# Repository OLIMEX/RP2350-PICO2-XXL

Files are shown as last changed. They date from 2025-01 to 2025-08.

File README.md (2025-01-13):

# RP2350-PICO2-XXL
RP2350B PICO2 development board exposing 48 GPIO

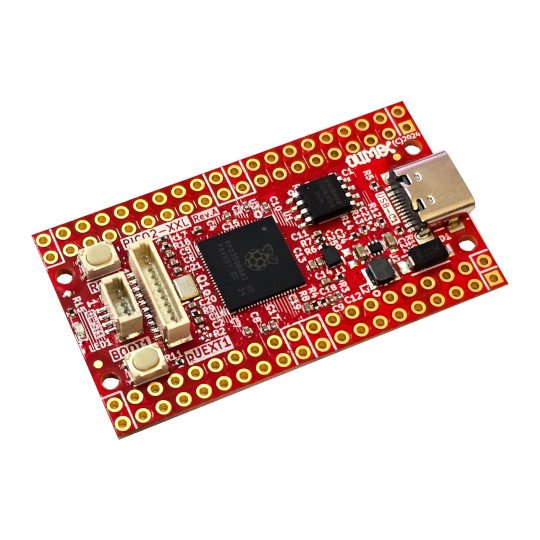
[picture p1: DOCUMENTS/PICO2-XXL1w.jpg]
PICO2-XXL1w


https://www.olimex.com/Products/RaspberryPi/PICO/PICO2-XXL/

## Licensee
* Hardware is released under CERN Open Hardware Licence Version 2 - Strongly Reciprocal
* Software is released under GPL V3 Licensee
* Documentation is released under CC BY-SA 4.0

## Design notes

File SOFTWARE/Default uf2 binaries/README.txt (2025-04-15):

Default uf2 binaries are the binaries we program the boards during testing and manufacturing.

These were last updated at the end of January before hardware revision B was released.

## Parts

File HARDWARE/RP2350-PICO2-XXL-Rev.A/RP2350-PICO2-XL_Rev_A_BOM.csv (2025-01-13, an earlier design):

Quantity | Value | Footprint | Reference
2 | YTS-A016-X | YTS-A016-X | BOOT1, RST1
13 | 100nF/10V/20%/X5R/C0402 | C_0402_5MIL_DWS | C1, C3, C4, C5, C6, C7, C8, C9, C10, C11, C12, C15, C17
5 | 4.7uF/10V/20%/X5R/C0402 | C_0402_5MIL_DWS | C13, C14, C16, C18, C19
2 | 27pF/50V/5%/C0G/C0402 | C_0402_5MIL_DWS | C20, C21
2 | 22uF/6.3V/20%/X5R/C0603 | C_0603_5MIL_DWS | C22, C24
1 | 1N5822/SS34/SMA | SMA-KA | D1
1 | 3.3uH/2.0A/DCR=140mR/20%/2.00x1.60x1.00mm/L2016(PIM201610-3R3MTS00) | L_2016_MM | L1
1 | 1.0uH/2.5A/DCR=30mR/20%/3.00x3.00x1.50mm/CD32(SWPA3015S1R0MT) | CD32 | L2
1 | LED/GREEN/0603 | LED_0603_KA | LED1
1 | Q12MHz/18pF/30ppm/4P/3.2x2.5mm(ABM8-12.000MHZ-D2Y-T) | TSX-3.2x2.5mm_GND(3) | Q1
1 | SH1.0-4P-180D | BM04B-SRSS-TB | QWST1
1 | 10k/R0402 | R_0402_5MIL_DWS | R1
1 | 33R/R0402 | R_0402_5MIL_DWS | R3
1 | 200R/1%/R0402 | R_0402_5MIL_DWS | R4
2 | 5.1k/1%/R0402 | R_0402_5MIL_DWS | R5, R10
2 | 27R/R0402 | R_0402_5MIL_DWS | R6, R7
1 | 1.3R/1%/R0402 | R_0402_5MIL_DWS | R8
2 | 1k/R0402 | R_0402_5MIL_DWS | R9, R11
1 | 1M/R0402 | R_0402_5MIL_DWS | R12
1 | 220k/R0402 | R_0402_5MIL_DWS | R13
1 | 49.9k/1%/R0402 | R_0402_5MIL_DWS | R14
3 | 2.2k/R0402 | R_0402_5MIL_DWS | R15, R17, R18
1 | W25Q16JVSSIQ | SO-8_208mil | U1
1 | TPS62A02ADRLR(SOT-563-6) | SOT-563-6 | U2
1 | RP2350B(QFN-80_10.00x10.00x0.90mm_P0.4mm) | QFN-80_10.00x10.00x0.90mm_P0.4mm | U3
1 | USB-C-16P-F(A40-00119-A52-12) | USB2.0_TYPE-C(A40-00119-A52-12)_Paste | USB-C1
1 | SH1.0-10P-180D | BM10B-SRSS-TB | pUEXT1

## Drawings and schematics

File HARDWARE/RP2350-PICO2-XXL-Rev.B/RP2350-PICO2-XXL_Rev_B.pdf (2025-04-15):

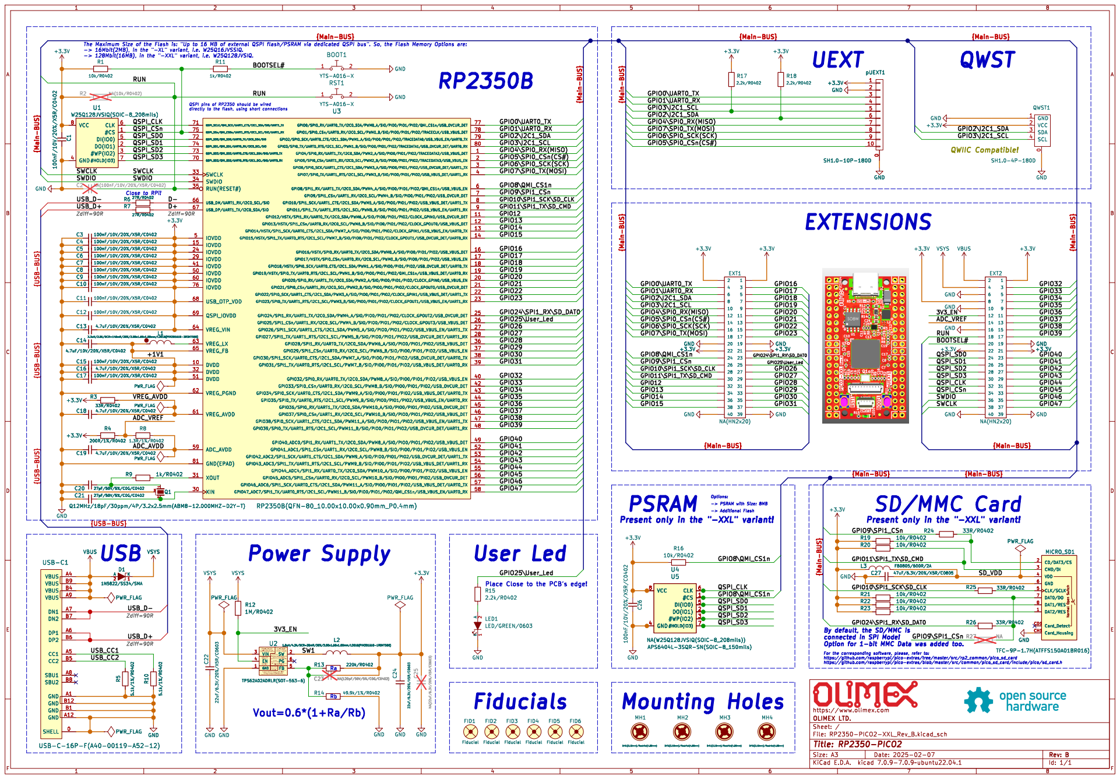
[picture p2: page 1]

Zdiff=90R {USB-BUS} {USB-BUS} {Main-BUS}
+3.3V GND

QSPI pins of RP2350 should be wired

Place Close to the PCB's edge!

Cout=(10~22)uF/6.3V/X5Rþÿ(Vout"e1.8V). 22uFRecommended! Cout=22uF/6.3V/X5Rþÿ(1.2V"dVout<1.8V) Cout=44uF/6.3V/X5Rþÿ(0.6V"dVout<1.2V) DCR<50mR

In casea loweroutputrippleisdesired,higheroutputcapacitancecanhelpreducetheripple. Lx=1.0uH

https://github.com/raspberrypi/pico-extras/blob/master/src/common/pico_sd_card/include/pico/sd_card.h

Donotfloat. Enablecontrol. FB Input Current,I(FB)=100nA(max) FeedbackReferenceVoltage,V(REF)=0.6V
Rb mustnotbehigherthanþÿ100k© toprovideacceptablenoisesensitivity. ShutdownCurrentI(SHDN)=0.01-2uA

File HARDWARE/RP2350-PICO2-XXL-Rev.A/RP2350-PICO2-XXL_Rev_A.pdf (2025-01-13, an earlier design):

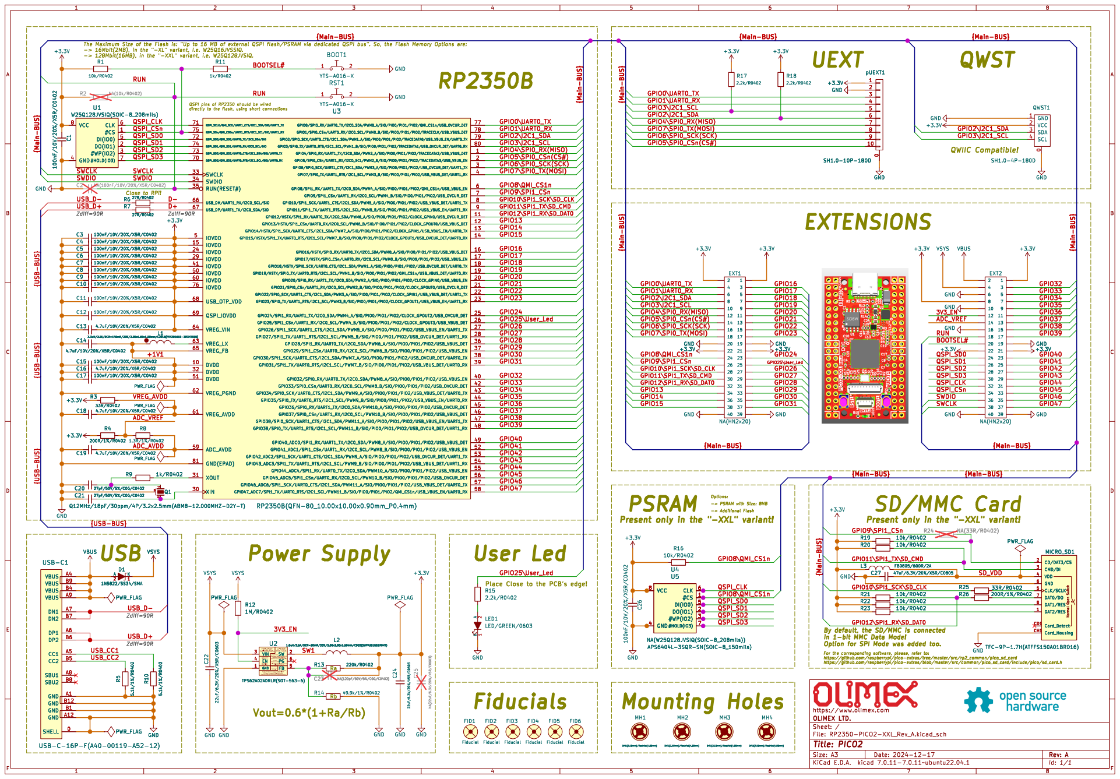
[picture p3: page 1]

QSPI pins of RP2350 should be wired
directly to the flash, using short connections

Place Close to the PCB's edge! Power Supply

Donotfloat. Enablecontrol. FB Input Current,I(FB)=100nA(max) FeedbackReferenceVoltage,V(REF)=0.6V
Rb mustnotbehigherthanþÿ100k© toprovideacceptablenoisesensitivity. ShutdownCurrentI(SHDN)=0.01-2uA
SwitchingFrequency 2.4MHz TPS62A02ADRLR V(ENH)=1.2V

In casea loweroutputrippleisdesired,higheroutputcapacitancecanhelpreducetheripple. Lx=1.0uH
Cout=(10~22)uF/6.3V/X5Rþÿ(Vout"e1.8V). 22uFRecommended! Cout=22uF/6.3V/X5Rþÿ(1.2V"dVout<1.8V) Cout=44uF/6.3V/X5Rþÿ(0.6V"dVout<1.2V) DCR<50mR

TPS62A02ADRLR(SOT-563-6)
Rb Vout=0.6*(1+Ra/Rb)

File: RP2350-PICO2-XXL_Rev_A.kicad_sch Sheet: / OLIMEX LTD. https://www.olimex.com

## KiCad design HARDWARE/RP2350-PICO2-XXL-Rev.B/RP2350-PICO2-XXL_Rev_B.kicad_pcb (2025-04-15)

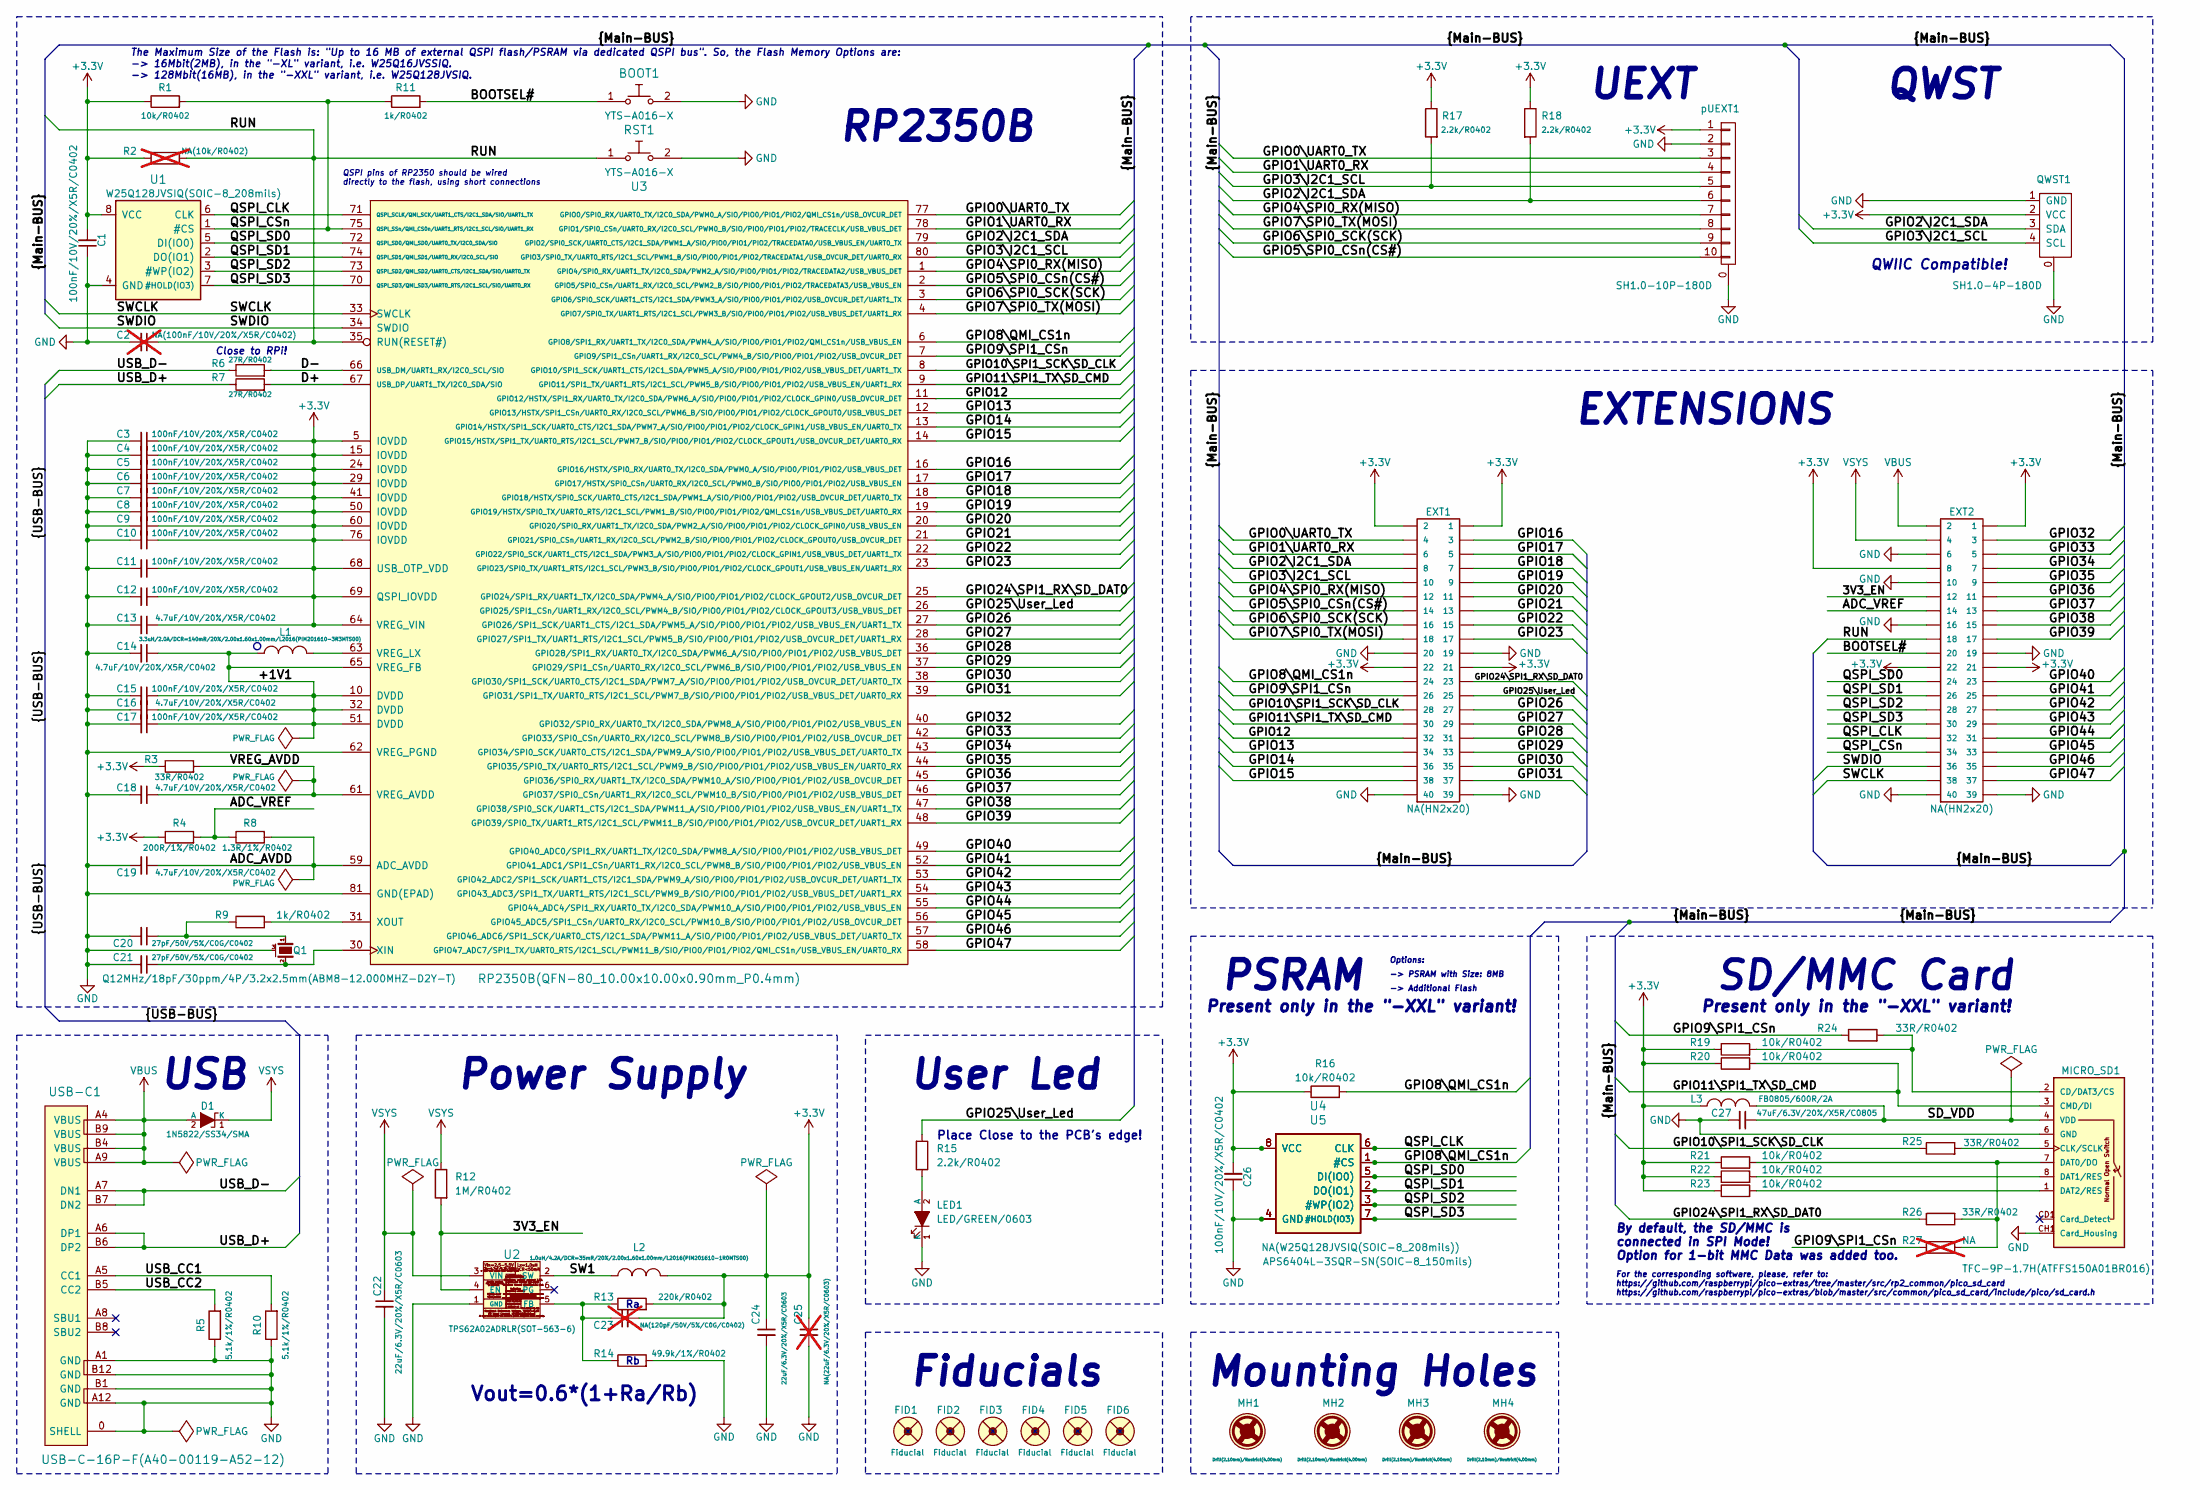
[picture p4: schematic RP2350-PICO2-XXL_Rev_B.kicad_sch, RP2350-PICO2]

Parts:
BOOT1: YTS-A016-X
C1, C3, C4, C5, C6, C7, C8, C9, C10, C11, C12, C15, C17, C26: 100nF/10V/20%/X5R/C0402; C_0402_5MIL_DWS
C2: NA(100nF/10V/20%/X5R/C0402); C_0402_5MIL_DWS; not fitted
C13, C14, C16, C18, C19: 4.7uF/10V/20%/X5R/C0402; C_0402_5MIL_DWS
C20, C21: 27pF/50V/5%/C0G/C0402; C_0402_5MIL_DWS
C22, C24: 22uF/6.3V/20%/X5R/C0603; C_0603_5MIL_DWS
C23: NA(120pF/50V/5%/C0G/C0402); C_0402_5MIL_DWS; not fitted
C25: NA(22uF/6.3V/20%/X5R/C0603); C_0603_5MIL_DWS; not fitted
C27: 47uF/6.3V/20%/X5R/C0805; C_0805_5MIL_DWS
D1: 1N5822/SS34/SMA; SMA-KA
EXT1, EXT2: NA(HN2x20); HN2x20
FID1, FID4: Fiducial; Fiducial1x3_Paste
FID2, FID3, FID5, FID6: Fiducial; Fiducial1x3
L1: 3.3uH/2.0A/DCR=140mR/20%/2.00x1.60x1.00mm/L2016(P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; L_2016_MM
L2: 1.0uH/4.2A/DCR=35mR/20%/2.00x1.60x1.00mm/L2016(PI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; L_2016_MM
L3: FB0805/600R/2A; L_0805_5MIL_DWS
LED1: LED/GREEN/0603; LED_0603_KA
MH1, MH2, MH3, MH4: Drill(2.10mm)/Restrict(4.00mm); Mounting_Hole_Drill-2.1mm_Clerance-4mm
MICRO_SD1: TFC-9P-1.7H(ATFFS150A01BR016); uSD(TFC-9P-1.xH(ATFFS150A01BR016))
Q1: Q12MHz/18pF/30ppm/4P/3.2x2.5mm(ABM8-12.000MHZ-D2Y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; TSX-3.2x2.5mm_GND(3)
QWST1: SH1.0-4P-180D; BM04B-SRSS-TB
R1, R16, R19, R20, R21, R22, R23: 10k/R0402; R_0402_5MIL_DWS
R2: NA(10k/R0402); R_0402_5MIL_DWS; not fitted
R3, R24, R25, R26: 33R/R0402; R_0402_5MIL_DWS
R4: 200R/1%/R0402; R_0402_5MIL_DWS
R5, R10: 5.1k/1%/R0402; R_0402_5MIL_DWS
R6, R7: 27R/R0402; R_0402_5MIL_DWS
R8: 1.3R/1%/R0402; R_0402_5MIL_DWS
R9, R11: 1k/R0402; R_0402_5MIL_DWS
R12: 1M/R0402; R_0402_5MIL_DWS
R13: 220k/R0402; R_0402_5MIL_DWS
R14: 49.9k/1%/R0402; R_0402_5MIL_DWS
R15, R17, R18: 2.2k/R0402; R_0402_5MIL_DWS
R27: NA; R_0402_5MIL_DWS; not fitted
RST1: YTS-A016-X
U1: W25Q128JVSIQ(SOIC-8_208mils); SO-8_208mil
U2: TPS62A02ADRLR(SOT-563-6); SOT-563-6
U3: RP2350B(QFN-80_10.00x10.00x0.90mm_P0.4mm); QFN-80_10.00x10.00x0.90mm_P0.4mm
U4: NA(W25Q128JVSIQ(SOIC-8_208mils)); SO-8_208mil
U5: APS6404L-3SQR-SN(SOIC-8_150mils); SO-8
USB-C1: USB-C-16P-F(A40-00119-A52-12); USB2.0_TYPE-C(A40-00119-A52-12)_Paste
pUEXT1: SH1.0-10P-180D; BM10B-SRSS-TB

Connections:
+3.3V: C1.2, C3.1, C4.1, C5.1, C6.1, C7.1, C8.1, C9.1, C10.1, C11.1, C12.1, C13.1, C23.2, C24.1, C25.1, C26.2, EXT1.1, EXT1.2, EXT1.21, EXT1.22, EXT2.1, EXT2.8, EXT2.21, EXT2.22, L2.1, L3.1, QWST1.2 (VCC), R1.1, R2.1, R3.1, R4.1, R13.2, R16.1, R17.1, R18.1, R19.1, R20.1, R21.1, R22.1, R23.1, U1.8 (VCC), U3.5 (IOVDD), U3.15 (IOVDD), U3.24 (IOVDD), U3.29 (IOVDD), U3.41 (IOVDD), U3.50 (IOVDD), U3.60 (IOVDD), U3.64 (VREG_VIN), U3.68 (USB_OTP_VDD), U3.69 (QSPI_IOVDD), U3.76 (IOVDD), U4.8 (VCC), U5.8 (VCC), pUEXT1.1
/3V3_EN: EXT2.12, R12.2, U2.4 (EN)
/+1V1: C14.1, C15.1, C16.1, C17.1, L1.1, U3.10 (DVDD), U3.32 (DVDD), U3.51 (DVDD), U3.65 (VREG_FB)
/ADC_AVDD: C19.1, R8.2, U3.59 (ADC_AVDD)
/ADC_VREF: EXT2.14, R4.2, R8.1
/BOOTSEL#: BOOT1.1, EXT2.20, R11.2
/D+: R7.2, U3.67 (USB_DP/UART1_TX/I2C0_SDA/SIO)
/D-: R6.2, U3.66 (USB_DM/UART1_RX/I2C0_SCL/SIO)
/GPIO0\UART0_TX: EXT1.4, U3.77 (GPIO0/SPI0_RX/UART0_TX/I2C0_SDA/PWM0_A/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), pUEXT1.3
/GPIO1\UART0_RX: EXT1.6, U3.78 (GPIO1/SPI0_CSn/UART0_RX/I2C0_SCL/PWM0_B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), pUEXT1.4
/GPIO2\I2C1_SDA: EXT1.8, QWST1.3 (SDA), R18.2, U3.79 (GPIO2/SPI0_SCK/UART0_CTS/I2C1_SDA/PWM1_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), pUEXT1.6
/GPIO3\I2C1_SCL: EXT1.10, QWST1.4 (SCL), R17.2, U3.80 (GPIO3/SPI0_TX/UART0_RTS/I2C1_SCL/PWM1_B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), pUEXT1.5
/GPIO4\SPI0_RX(MISO): EXT1.12, U3.1 (GPIO4/SPI0_RX/UART1_TX/I2C0_SDA/PWM2_A/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), pUEXT1.7
/GPIO5\SPI0_CSn(CS#): EXT1.14, U3.2 (GPIO5/SPI0_CSn/UART1_RX/I2C0_SCL/PWM2_B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), pUEXT1.10
/GPIO6\SPI0_SCK(SCK): EXT1.16, U3.3 (GPIO6/SPI0_SCK/UART1_CTS/I2C1_SDA/PWM3_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), pUEXT1.9
/GPIO7\SPI0_TX(MOSI): EXT1.18, U3.4 (GPIO7/SPI0_TX/UART1_RTS/I2C1_SCL/PWM3_B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), pUEXT1.8
/GPIO8\QMI_CS1n: EXT1.24, R16.2, U3.6 (GPIO8/SPI1_RX/UART1_TX/I2C0_SDA/PWM4_A/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), U4.1 (#CS), U5.1 (#CS)
/GPIO9\SPI1_CSn: EXT1.26, R24.1, R27.1, U3.7 (GPIO9/SPI1_CSn/UART1_RX/I2C0_SCL/PWM4_B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)
/GPIO10\SPI1_SCK\SD_CLK: EXT1.28, R25.1, U3.8 (GPIO10/SPI1_SCK/UART1_CTS/I2C1_SDA/PWM5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)
/GPIO11\SPI1_TX\SD_CMD: EXT1.30, MICRO_SD1.3 (CMD/DI), R20.2, U3.9 (GPIO11/SPI1_TX/UART1_RTS/I2C1_SCL/PWM5_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)
/GPIO12: EXT1.32, U3.11 (GPIO12/HSTX/SPI1_RX/UART0_TX/I2C0_SDA/P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)
/GPIO13: EXT1.34, U3.12 (GPIO13/HSTX/SPI1_CSn/UART0_RX/I2C0_SCL/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)
/GPIO14: EXT1.36, U3.13 (GPIO14/HSTX/SPI1_SCK/UART0_CTS/I2C1_SDA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)
/GPIO15: EXT1.38, U3.14 (GPIO15/HSTX/SPI1_TX/UART0_RTS/I2C1_SCL/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)
/GPIO16: EXT1.3, U3.16 (GPIO16/HSTX/SPI0_RX/UART0_TX/I2C0_SDA/P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)
/GPIO17: EXT1.5, U3.17 (GPIO17/HSTX/SPI0_CSn/UART0_RX/I2C0_SCL/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)
/GPIO18: EXT1.7, U3.18 (GPIO18/HSTX/SPI0_SCK/UART0_CTS/I2C1_SDA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)
/GPIO19: EXT1.9, U3.19 (GPIO19/HSTX/SPI0_TX/UART0_RTS/I2C1_SCL/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)
/GPIO20: EXT1.11, U3.20 (GPIO20/SPI0_RX/UART1_TX/I2C0_SDA/PWM2_A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)
/GPIO21: EXT1.13, U3.21 (GPIO21/SPI0_CSn/UART1_RX/I2C0_SCL/PWM2_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)
/GPIO22: EXT1.15, U3.22 (GPIO22/SPI0_SCK/UART1_CTS/I2C1_SDA/PWM3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)
/GPIO23: EXT1.17, U3.23 (GPIO23/SPI0_TX/UART1_RTS/I2C1_SCL/PWM3_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)
/GPIO24\SPI1_RX\SD_DAT0: EXT1.23, R26.1, U3.25 (GPIO24/SPI1_RX/UART1_TX/I2C0_SDA/PWM4_A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)
/GPIO25\User_Led: EXT1.25, R15.2, U3.26 (GPIO25/SPI1_CSn/UART1_RX/I2C0_SCL/PWM4_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)
/GPIO26: EXT1.27, U3.27 (GPIO26/SPI1_SCK/UART1_CTS/I2C1_SDA/PWM5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)
/GPIO27: EXT1.29, U3.28 (GPIO27/SPI1_TX/UART1_RTS/I2C1_SCL/PWM5_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)
/GPIO28: EXT1.31, U3.36 (GPIO28/SPI1_RX/UART0_TX/I2C0_SDA/PWM6_A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)
/GPIO29: EXT1.33, U3.37 (GPIO29/SPI1_CSn/UART0_RX/I2C0_SCL/PWM6_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)
/GPIO30: EXT1.35, U3.38 (GPIO30/SPI1_SCK/UART0_CTS/I2C1_SDA/PWM7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)
/GPIO31: EXT1.37, U3.39 (GPIO31/SPI1_TX/UART0_RTS/I2C1_SCL/PWM7_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)
/GPIO32: EXT2.3, U3.40 (GPIO32/SPI0_RX/UART0_TX/I2C0_SDA/PWM8_A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)
/GPIO33: EXT2.5, U3.42 (GPIO33/SPI0_CSn/UART0_RX/I2C0_SCL/PWM8_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)
/GPIO34: EXT2.7, U3.43 (GPIO34/SPI0_SCK/UART0_CTS/I2C1_SDA/PWM9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)
/GPIO35: EXT2.9, U3.44 (GPIO35/SPI0_TX/UART0_RTS/I2C1_SCL/PWM9_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)
/GPIO36: EXT2.11, U3.45 (GPIO36/SPI0_RX/UART1_TX/I2C0_SDA/PWM10_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)
/GPIO37: EXT2.13, U3.46 (GPIO37/SPI0_CSn/UART1_RX/I2C0_SCL/PWM10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)
/GPIO38: EXT2.15, U3.47 (GPIO38/SPI0_SCK/UART1_CTS/I2C1_SDA/PWM1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)
/GPIO39: EXT2.17, U3.48 (GPIO39/SPI0_TX/UART1_RTS/I2C1_SCL/PWM11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)
/GPIO40: EXT2.23, U3.49 (GPIO40_ADC0/SPI1_RX/UART1_TX/I2C0_SDA/P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)
/GPIO41: EXT2.25, U3.52 (GPIO41_ADC1/SPI1_CSn/UART1_RX/I2C0_SCL/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)
/GPIO42: EXT2.27, U3.53 (GPIO42_ADC2/SPI1_SCK/UART1_CTS/I2C1_SDA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)
/GPIO43: EXT2.29, U3.54 (GPIO43_ADC3/SPI1_TX/UART1_RTS/I2C1_SCL/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)
/GPIO44: EXT2.31, U3.55 (GPIO44_ADC4/SPI1_RX/UART0_TX/I2C0_SDA/P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)
/GPIO45: EXT2.33, U3.56 (GPIO45_ADC5/SPI1_CSn/UART0_RX/I2C0_SCL/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)
/GPIO46: EXT2.35, U3.57 (GPIO46_ADC6/SPI1_SCK/UART0_CTS/I2C1_SDA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)
/GPIO47: EXT2.37, U3.58 (GPIO47_ADC7/SPI1_TX/UART0_RTS/I2C1_SCL/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)
/QSPI_CLK: EXT2.32, U1.6 (CLK), U3.71 (QSPI_SCLK/QMI_SCK/UART1_CTS/I2C1_SDA/SI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), U4.6 (CLK), U5.6 (CLK)
/QSPI_CSn: EXT2.34, R1.2, R11.1, U1.1 (#CS), U3.75 (QSPI_SSn/QMI_CS0n/UART1_RTS/I2C1_SCL/SI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)
/QSPI_SD0: EXT2.24, U1.5 (DI(IO0)), U3.72 (QSPI_SD0/QMI_SD0/UART0_TX/I2C0_SDA/SIO), U4.5 (DI(IO0)), U5.5 (DI(IO0))
/QSPI_SD1: EXT2.26, U1.2 (DO(IO1)), U3.74 (QSPI_SD1/QMI_SD1/UART0_RX/I2C0_SCL/SIO), U4.2 (DO(IO1)), U5.2 (DO(IO1))
/QSPI_SD2: EXT2.28, U1.3 (#WP(IO2)), U3.73 (QSPI_SD2/QMI_SD2/UART0_CTS/I2C1_SDA/SIO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), U4.3 (#WP(IO2)), U5.3 (#WP(IO2))
/QSPI_SD3: EXT2.30, U1.7 (#HOLD(IO3)), U3.70 (QSPI_SD3/QMI_SD3/UART0_RTS/I2C1_SCL/SIO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), U4.7 (#HOLD(IO3)), U5.7 (#HOLD(IO3))
/RUN: C2.1, EXT2.18, R2.2, RST1.1, U3.35 (RUN(RESET#))
/SD_VDD: C27.1, L3.2, MICRO_SD1.4 (VDD)
/SW1: L2.2, U2.2 (SW)
/SWCLK: EXT2.38, U3.33 (SWCLK)
/SWDIO: EXT2.36, U3.34 (SWDIO)
/USB_CC1: R10.2, USB-C1.A5 (CC1)
/USB_CC2: R5.2, USB-C1.B5 (CC2)
/USB_D+: R7.1, USB-C1.A6 (DP1), USB-C1.B6 (DP2)
/USB_D-: R6.1, USB-C1.A7 (DN1), USB-C1.B7 (DN2)
/VREG_AVDD: C18.1, R3.2, U3.61 (VREG_AVDD)
GND: BOOT1.2, C1.1, C2.2, C3.2, C4.2, C5.2, C6.2, C7.2, C8.2, C9.2, C10.2, C11.2, C12.2, C13.2, C14.2, C15.2, C16.2, C17.2, C18.2, C19.2, C20.2, C21.2, C22.2, C24.2, C25.2, C26.1, C27.2, EXT1.19, EXT1.20, EXT1.39, EXT1.40, EXT2.6, EXT2.10, EXT2.16, EXT2.19, EXT2.39, EXT2.40, LED1.1 (K), MICRO_SD1.6 (GND), MICRO_SD1.CH1 (Card_Housing), Q1.3 (case), QWST1.0, QWST1.1 (GND), R5.1, R10.1, R14.2, RST1.2, U1.4 (GND), U2.1 (GND), U3.62 (VREG_PGND), U3.81 (GND(EPAD)), U4.4 (GND), U5.4 (GND), USB-C1.0 (SHELL), USB-C1.A1 (GND), USB-C1.A12 (GND), USB-C1.B1 (GND), USB-C1.B12 (GND), pUEXT1.0, pUEXT1.2
unnamed: C20.1, Q1.1, R9.1
unnamed: LED1.2 (A), R15.1
unnamed: MICRO_SD1.2 (CD/DAT3/CS), R19.2, R24.2
unnamed: MICRO_SD1.5 (CLK/SCLK), R25.2
unnamed: MICRO_SD1.7 (DAT0/DO), R21.2, R26.2, R27.2
unnamed: MICRO_SD1.8 (DAT1/RES), R22.2
unnamed: MICRO_SD1.1 (DAT2/RES), R23.2
unnamed: C23.1, R13.1, R14.1, U2.5 (FB)
unnamed: L1.2, U3.63 (VREG_LX)
unnamed: C21.1, Q1.2, U3.30 (XIN)
unnamed: R9.2, U3.31 (XOUT)
VBUS: D1.2 (A), EXT2.2, USB-C1.A4 (VBUS), USB-C1.A9 (VBUS), USB-C1.B4 (VBUS), USB-C1.B9 (VBUS)
VSYS: C22.1, D1.1 (K), EXT2.4, R12.1, U2.3 (VIN)

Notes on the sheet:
Present only in the "-XXL" variant!
EXTENSIONS
QSPI pins of RP2350 should be wired directly to the flash, using short connections
-> PSRAM with Size: 8MB
By default, the SD/MMC is connected in SPI Mode! Option for 1-bit MMC Data was added too.
The Maximum Size of the Flash is: "Up to 16 MB of external QSPI flash/PSRAM via dedicated QSPI bus". So, the Flash Memory Options are: -> 16Mbit(2MB), in the "-XL" variant, i.e. W25Q16JVSSIQ. -> 128Mbit(16MB), in the "-XXL" variant, i.e. W25Q128JVSIQ.
SD/MMC Card
QWST
USB
User Led
For the corresponding software, please, refer to: https://github.com/raspberrypi/pico-extras/tree/master/src/rp2_common/pico_sd_card https://github.com/raspberrypi/pico-extras/blob/master/src/common/pico_sd_card/include/pico/sd_card.h
Options:
-> Additional Flash
QWIIC Compatible!
Place Close to the PCB's edge!
Close to RPi!
RP2350B
Vout=0.6*(1+Ra/Rb)
Mounting Holes
Power Supply
PSRAM
Fiducials
UEXT

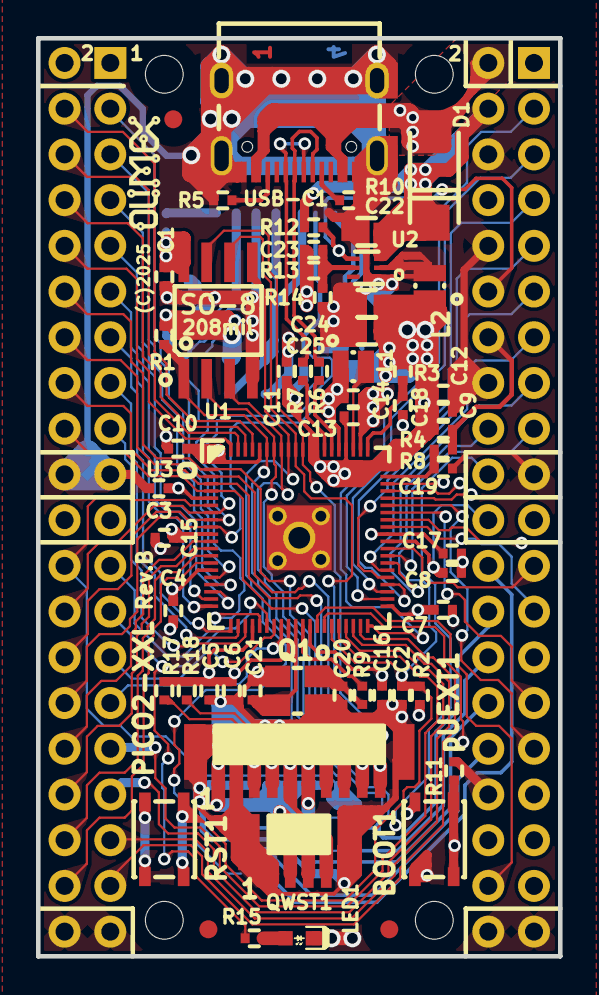
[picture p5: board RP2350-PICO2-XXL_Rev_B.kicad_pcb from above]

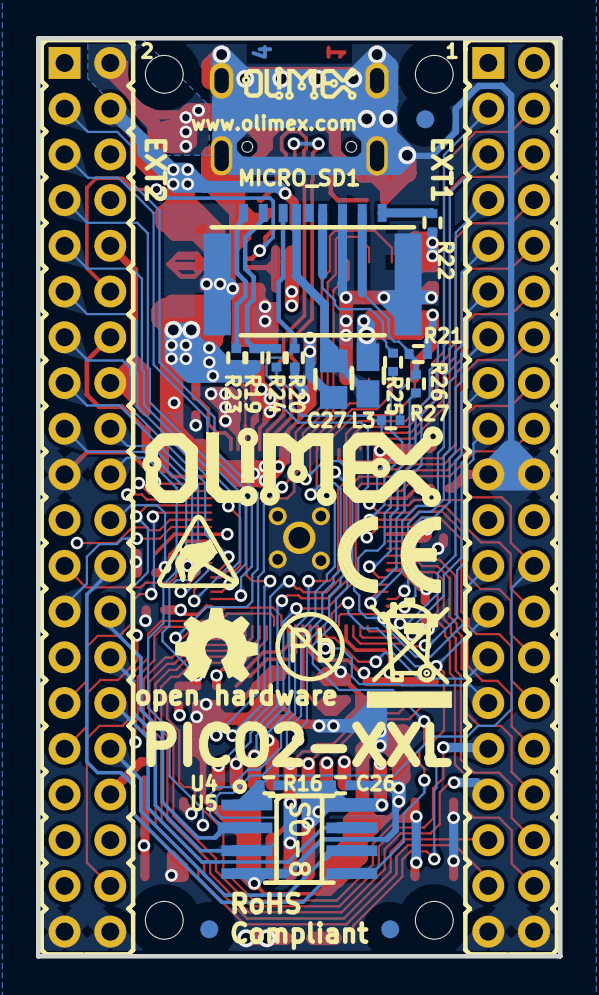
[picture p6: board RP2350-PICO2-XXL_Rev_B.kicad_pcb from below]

Board: 4 copper layers, 29.0 x 51.0 mm, 91 parts (28 on the bottom side), 86 nets.

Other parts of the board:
Logo_OLIMEX_80, Logo_OLIMEX_80-Bot: Logo_OLIMEX_80
Logo_OLIMEX_TB: Logo_OLIMEX_TB
Sign_Antistatic_Small: Sign_Antistatic; Sign_Antistatic_4.5mmX2.8mm
Sign_CE: CE_Sign
Sign_OSHW_7.3x6.0mm: Sign_OSHW_7.3x6.0mm; Sign_OSHW_7.3x6.0mmn
Sign_PB-Free: Sign_PB-Free
Sign_RecycleBin_1: Sign_RecycleBin_1

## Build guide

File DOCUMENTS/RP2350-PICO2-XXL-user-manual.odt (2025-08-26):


RP2350-PICO2-XL

RP2350-PICO2-XXL

User Manual

Document 2.1 August 2025 www.olimex.com

# Introduction to RP2350-PICO2-XXL

RP2350-PICO2-XXL (https://www.olimex.com/Products/RaspberryPi/PICO/PICO2-XXL/open-source-hardware) is a re-design of the popular “Raspberry Pi Pico 2” board with these improvements:

- RP2350B Dual Cortex-M33 or dual RISC-V @ 150MHz
- All 48 RP2350 GPIOs exposed to the user
- USB-C connector for data and powering – it allows more current to be supplied to the board
- DCDC power supply voltage regulator 3.3V 2A (3A peak)
- 2MB or 16MB flash memory versions (-XL and -XXL variants)
- Extra 8MB PSRAM in the -XXL variant
- Micro SD card connector in the -XXL variant
- BOOT and RESET buttons
- Four-layer board for better noise immunity and USB differential pair routing
- UEXT connector (pUEXT 1.0 mm step connector)
- Qwiic/Stemma connector
- Status LED
- Dimensions: (50 x 28)mm ~ (1.97 x 1.10)"

Notice

The two board variants RP2350-PICO2-XL (https://www.olimex.com/Products/RaspberryPi/PICO/RP2350-PICO2-XL/open-source-hardware) and RP2350-PICO2-XXL (https://www.olimex.com/Products/RaspberryPi/PICO/PICO2-XXL/open-source-hardware) share the same PCB and silksreen! The three differences between -XL and -XXL variants are that:

- the -XXL variant has PSRAM,the -XL variant – no PSRAM;

- the -XXL variant has micro SD card, the -XL variant – no micro SD card connector;

- the -XXL has 16MB of flash memory, the flash memory of the -XL variant is only 2MB.

# Order codes for RP2350-PICO2-XXL and accessories

RP2350-PICO2-XL (https://www.olimex.com/Products/RaspberryPi/PICO/RP2350-PICO2-XL/open-source-hardware) industrial grade RP2350-PICO2 board with 48 GPIOs exposed

RP2350-PICO2-XXL (https://www.olimex.com/Products/RaspberryPi/PICO/RP2350-PICO2-XL/open-source-hardware) includes everything in XL, bigger flash, extra 8MB PSRAM, and extra microSD card

USB-CABLE-AM-USB3-C (https://www.olimex.com/Products/Components/Cables/USB-CABLE-AM-USB3-C/) high quality USB 3.0 cable with type C connector for power and programming

pUEXT pack of cables (https://www.olimex.com/Products/Modules/Adapters/pUEXT-CABLE-10-10-200MM/) pack of 3pcs 200mm pUEXT cables

UEXT-MPQ (https://www.olimex.com/Products/Modules/Adapters/UEXT-MPQ/open-source-hardware) converter board from pUEXT to UEXT

UEXT-PQ (https://www.olimex.com/Products/Modules/Adapters/UEXT-PQ/open-source-hardware) another converter board from pUEXT

# HARDWARE

## RP2350-PICO2-XXL layout

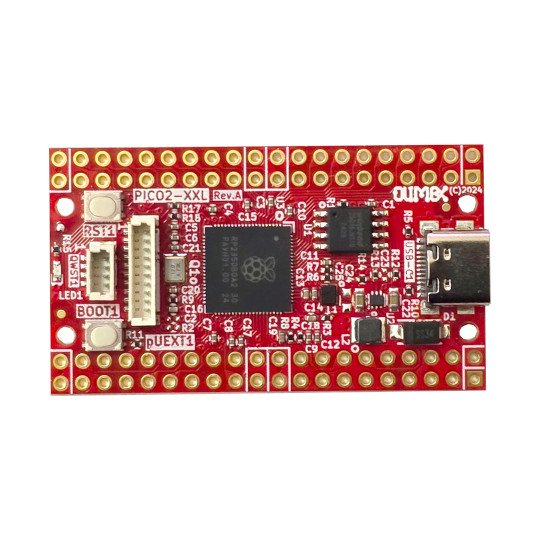
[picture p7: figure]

Top view for both -XL and -XXL

Power supply

USB-C

2MB or 16MB Flash

RP2350B

pUEXT

RST1 reset button

LED

Qwiic Stemma

Boot button

Bottom view for -XL variant:

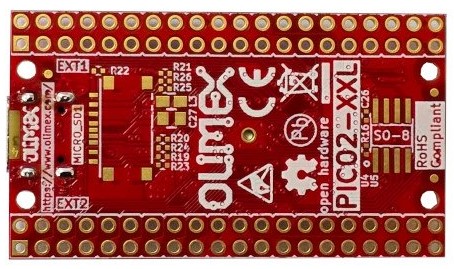
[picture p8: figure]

Bottom view for -XXL variant:

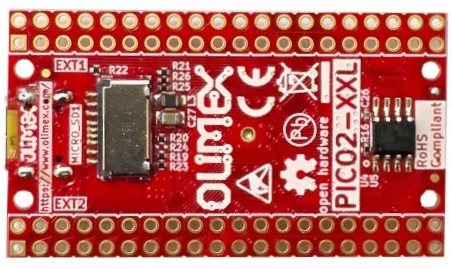
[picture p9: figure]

Micro SD card

8MB PSRAM

## RP2350-PICO2-XXL GPIOs

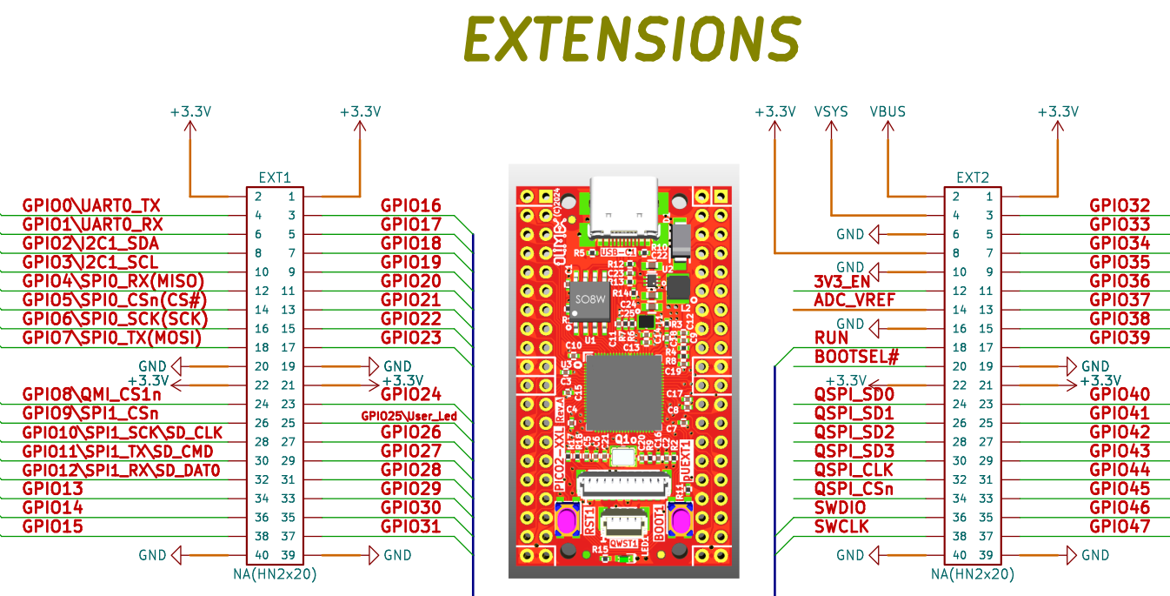
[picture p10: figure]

POWER SUPPLY:

VBUS +5V from, USB-C output

VDD_SYS +5V may be output or input

if you want to use as input i.e. to feed power from external 5V to this line make sure the board is not connected to USB!

when you use it as output i.e. you feed external electronics from it up to 1A @ 5V

+3.3V output which can source up to 2A @ 3.3V

3V3_EN input, when pulled to GND stops the 3.3V DCDC convertor

## RP2350-PICO2-XXL schematics

RP2350-PICO2-XXL (https://www.olimex.com/Products/RaspberryPi/PICO/RP2350-PICO2-XL/open-source-hardware) schematics can be found at GitHub (https://github.com/OLIMEX/RP2350-PICO2-XXL/tree/main/HARDWARE):

https://github.com/OLIMEX/RP2350-PICO2-XXL/tree/main/HARDWARE

## UEXT connector

UEXT connector stands for Universal EXTension connector and contains +3.3V, GND, I2C, SPI, UART signals.

UEXT connector can be in different shapes.

The original UEXT connector is 0.1” 2.54mm step boxed plastic connector. All signals are with 3.3V levels.

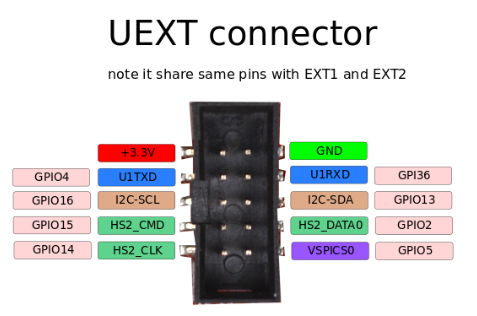
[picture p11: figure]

As the boards become smaller and smaller some smaller packages were introduced too beside the original UEXT connector:

- mUEXT is 1.27 mm step boxed header connector which is with same layout as UEXT;

- pUEXT is 1.0 mm single row connector (this is the connector used in RP2040-PICO30).

Olimex has developed number of MODULES (https://www.olimex.com/Products/Modules/) with this connector. There are temperature, humidity, pressure, magnetic field, light sensors. Modules with LCDs, LED matrix, Relays, Bluetooth, Zigbee, WiFi, GSM, GPS, RFID, RTC, EKG, sensors and etc.

## pUEXT signals

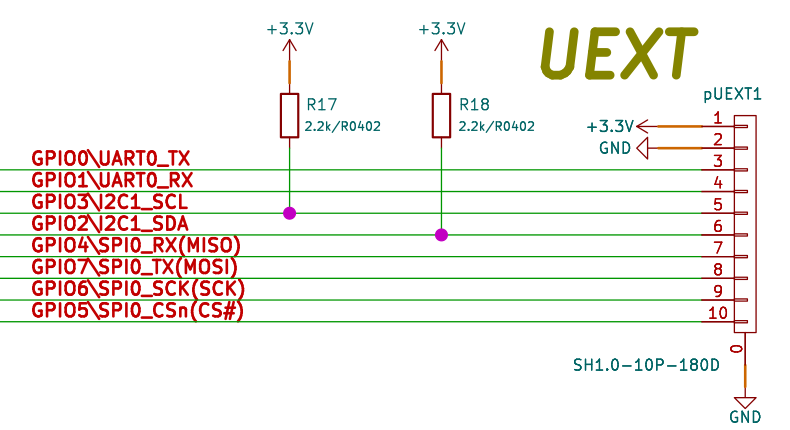
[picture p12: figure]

## Qwiic/Stemma connector

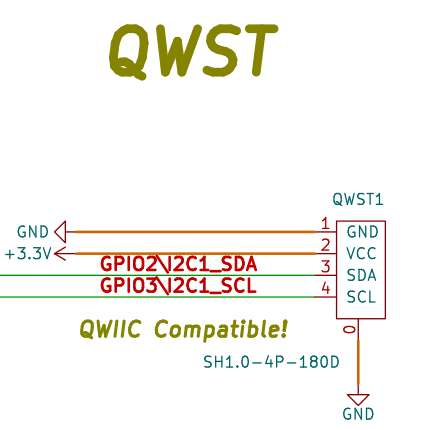
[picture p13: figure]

## Micro SD card connector

In latest hardware revisions (B and newer) the SD card is connected in SPI data mode:

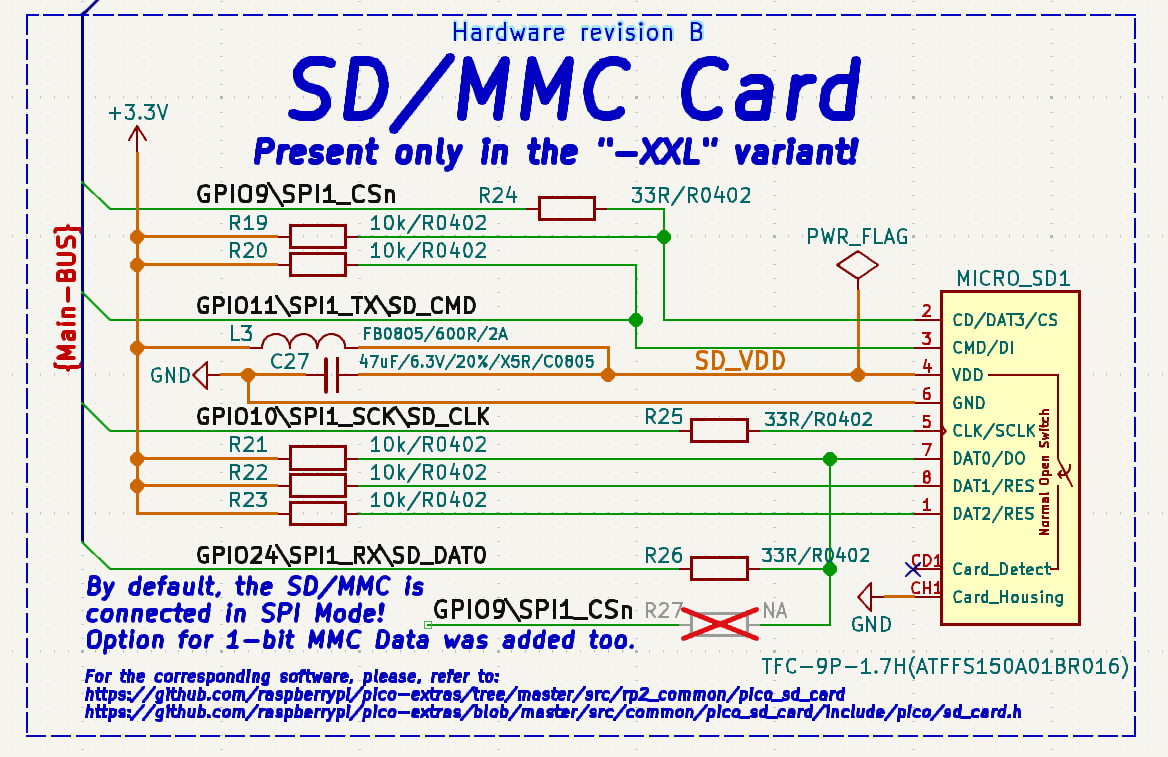
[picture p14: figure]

Notice that in hardware revision A the board was connected in 1-bit MMC data mode.

## PSRAM connection

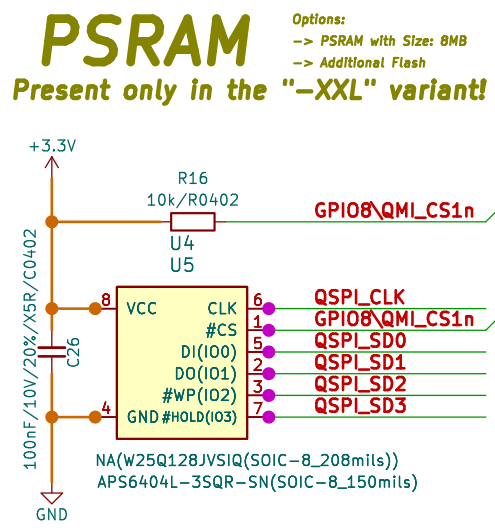
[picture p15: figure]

## LED connection

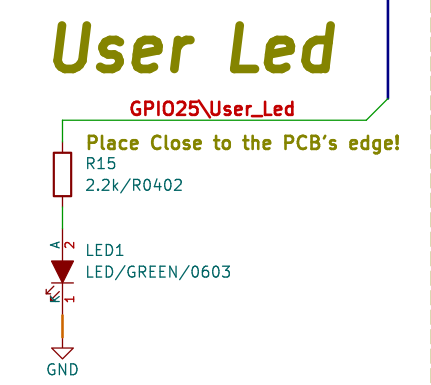
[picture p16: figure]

# SOFTWARE

RP2350-PICO2-XXL uses same software as PICO2

- Raspberry PI SDK, header can be found at this GitHub link (https://github.com/OLIMEX/RP2350-PICO2-XXL/blob/main/SOFTWARE/Pico%20SDK%202.1.1%20header/olimex_rp2350b_pico2.h)
- MicroPython SDK (note that to the current date RP2350B chip support is not implemented in MicroPython and the access of the GPIO30-47 in MicroPython is not implemented.
- CircuitPython from Adafruit – all 48 GPIOs are implemented.

Original production binaries can be found at the GitHub link here (https://github.com/OLIMEX/RP2350-PICO2-XXL/tree/main/SOFTWARE/Default%20uf2%20binaries)

# Document Revision History

Revision 2.1 August 2025

- Improved formatting

Revision 2.0 April 2025

- Added latest schematics

- Improved formatting

Revision 1.0 January 2025

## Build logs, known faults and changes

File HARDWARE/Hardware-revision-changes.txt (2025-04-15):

Deisgn made with KiCAD.

RP2350-PICO2-XXL notable hardware revisions changes:

Hardware revision B:

1. SD card now in SPI mode by default;
2. SD_DAT0 changed from "GPIO12\SPI1_RX\SD_DAT0" to "GPIO24\SPI1_RX\SD_DAT0" to avoid multiplexing;
3. Added R27 to provide an option for 1-bit mode and to change SD_DAT0 to GPIO9\SPI1_CSn;
4. Changed L2 package L_20_16_MM and value 1.0uH/4.2A/DCR=35mR/20%/2.00x1.60x1.00mm/L2016(PIM201610-1R0MTS00).
---

Hardware revision A:

Initial board release.

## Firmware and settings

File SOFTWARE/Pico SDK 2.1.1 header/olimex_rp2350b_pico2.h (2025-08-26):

/*
 * Copyright (c) 2020 Raspberry Pi (Trading) Ltd.
 *
 * SPDX-License-Identifier: BSD-3-Clause
 */

// -----------------------------------------------------
// NOTE: THIS HEADER IS ALSO INCLUDED BY ASSEMBLER SO
//       SHOULD ONLY CONSIST OF PREPROCESSOR DIRECTIVES
// -----------------------------------------------------

// This header may be included by other board headers as "boards/pimoroni_pico_plus2_rp2350.h"

// pico_cmake_set PICO_PLATFORM=rp2350

#ifndef _BOARDS_OLIMEX_PICO2_RP2350B_XXL_H
#define _BOARDS_OLIMEX_PICO2_RP2350B_XXL_H

// For board detection
#define OLIMEX_PICO2_RP2350B_XXL

// --- BOARD SPECIFIC ---

#define UEXT_UART 0
#define UEXT_UART_TX_PIN 0
#define UEXT_UART_RX_PIN 1
#define UEXT_I2C 1
#define UEXT_I2C_SCL_PIN 3
#define UEXT_I2C_SDA_PIN 2
#define UEXT_SPI 0
#define UEXT_SPI0_TX_MOSI_PIN 4
#define UEXT_SPIO_RX_MISO_PIN 7
#define UEXT_SPI0_SCK_PIN 6
#define UEXT_SPI0_CS_PIN 5

#define QWST_I2C 1
#define QWST_I2C_SCL_PIN 3
#define QWST_I2C_SDA_PIN 2

#define OLIMEX_PICO2_RP2350B_PSRAM_CS_PIN 8

// --- UART ---
#ifndef PICO_DEFAULT_UART
#define PICO_DEFAULT_UART 0
#endif
#ifndef PICO_DEFAULT_UART_TX_PIN
#define PICO_DEFAULT_UART_TX_PIN UEXT_UART_TX_PIN
#endif
#ifndef PICO_DEFAULT_UART_RX_PIN
#define PICO_DEFAULT_UART_RX_PIN UEXT_UART_RX_PIN
#endif

// --- LED ---
#ifndef PICO_DEFAULT_LED_PIN
#define PICO_DEFAULT_LED_PIN 25
#endif
// no PICO_DEFAULT_WS2812_PIN

// --- I2C ---
#ifndef PICO_DEFAULT_I2C
#define PICO_DEFAULT_I2C 1
#endif
#ifndef PICO_DEFAULT_I2C_SDA_PIN
#define PICO_DEFAULT_I2C_SDA_PIN UEXT_I2C_SDA_PIN
#endif
#ifndef PICO_DEFAULT_I2C_SCL_PIN
#define PICO_DEFAULT_I2C_SCL_PIN UEXT_I2C_SCL_PIN
#endif

// --- SPI ---
#ifndef PICO_DEFAULT_SPI
#define PICO_DEFAULT_SPI 0
#endif
#ifndef PICO_DEFAULT_SPI_SCK_PIN
#define PICO_DEFAULT_SPI_SCK_PIN SPCE_NETLIGHT_SCK_PIN
#endif
#ifndef PICO_DEFAULT_SPI_TX_PIN
#define PICO_DEFAULT_SPI_TX_PIN SPCE_RESET_MOSI_PIN
#endif
#ifndef PICO_DEFAULT_SPI_RX_PIN
#define PICO_DEFAULT_SPI_RX_PIN SPCE_TX_MISO_PIN
#endif
#ifndef PICO_DEFAULT_SPI_CSN_PIN
#define PICO_DEFAULT_SPI_CSN_PIN SPCE_RX_CS_PIN
#endif

// --- FLASH ---

#define PICO_BOOT_STAGE2_CHOOSE_W25Q080 1

#ifndef PICO_FLASH_SPI_CLKDIV
#define PICO_FLASH_SPI_CLKDIV 2
#endif

// pico_cmake_set_default PICO_FLASH_SIZE_BYTES = (16 * 1024 * 1024)
#ifndef PICO_FLASH_SIZE_BYTES
#define PICO_FLASH_SIZE_BYTES (16 * 1024 * 1024)
#endif

// The GPIO Pin used to read VBUS to determine if the device is battery powered.
#ifndef PICO_VBUS_PIN
#define PICO_VBUS_PIN 24
#endif

// The GPIO Pin used to monitor VSYS. Typically you would use this with ADC.
// There is an example in adc/read_vsys in pico-examples.
#ifndef PICO_VSYS_PIN
#define PICO_VSYS_PIN 43
#endif

// --- RP2350 VARIANT ---
#define PICO_RP2350B 1

// pico_cmake_set_default PICO_RP2350_A2_SUPPORTED = 1
#ifndef PICO_RP2350_A2_SUPPORTED
#define PICO_RP2350_A2_SUPPORTED 1
#endif



#endif

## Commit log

2025-04-15 Update
    Latest hardware revision and revision changes log
    [RP2350-PICO2-XXL_Rev_B-B_Cu.gbr, RP2350-PICO2-XXL_Rev_B-B_Mask.gbr, RP2350-PICO2-XXL_Rev_B-B_Paste.gbr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]
2025-04-15 Update
    Added uf2 files we program the boards.

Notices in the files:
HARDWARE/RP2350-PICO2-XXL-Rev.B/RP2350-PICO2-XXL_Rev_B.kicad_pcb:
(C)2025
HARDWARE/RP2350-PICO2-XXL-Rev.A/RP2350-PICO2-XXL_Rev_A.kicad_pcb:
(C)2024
